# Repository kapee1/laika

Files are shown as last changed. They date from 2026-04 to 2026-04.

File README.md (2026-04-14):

# Laika - 45%-ish v4n4g0n-inspired keyboard  



### Build guide — *coming soon*

---

### Main features:

* Custom compact layout — 47 keys + half of number row
* Waveshare RP2040-Zero MCU
* MX hotswap
* Split spacebar support (2 × 3u or 1 x 6u)
* Two plate options: Standard and Extra (extra plate has enlarged stabilizers holes)
* Top mount with o-rings
* The two halves of the case and top weight are held together by magnets
* VIAL / QMK firmware

---

### Layout:

laika

---

## BOM:

| Part | Quantity |
|---|---|
| Laika PCB | 1 |
| Laika Case Top | 1 |
| Laika Case Bottom | 1 |
| Laika Plate (Standard or Extra) | 1 |
| Top Weight | 1 |
| Battery Cover (optional) | 1 |
| Waveshare RP2040-Zero | 1 |
| 1N4148W SOD-123 Diodes | 53 |
| MX-compatible switches | 53 |
| MX hotswap sockets | 53 |
| Stabilizers (PCB-mount) | 2x3u or 1x6u |
| M2 screws x 4 mm | 10 |
| M2 inserts OD:3.2, H:3 | 8 |
| Rubber feet 3M SJ5302 (8x8x2) | 4 |
| Magnets 5x3 | 14 |
| Magnets 5x1 | 4 |
| Silicone o-rings 5x2 | 8 |

---

## Files:

```
laika/
├── case/
│   ├── top.step                          # Top case
│   ├── bottom.step                       # Bottom case
│   ├── battery-cover.step                # Battery cover
│   ├── standart-plate.step               # Standard plate
│   ├── extra-plate.step                  # Extra plate
│   ├── top-weight (laika).step           # Top weight — "laika" text
│   └── top-weight (laika-the-keyboard).step  # Top weight — "laika the keyboard" text
├── laika-pcb/
│   ├── laika-pcb.kicad_pcb               # PCB layout (KiCad 10)
│   ├── laika-pcb.kicad_sch               # Schematic (KiCad 10)
│   ├── laika-pcb.kicad_pro               # KiCad project
│   └── Production files/
│       └── Laika PCB gerbers.zip         # Ready-to-order gerber files
└── plate-dxf/
    ├── standart-plate.dxf                # Standard plate for laser cutting / CNC
    └── extra-plate.dxf                   # Extra plate with enlarged stabilizers cutouts / CNC
```

---

## PCB manufacturing:

Send `laika-pcb/Production files/Laika PCB gerbers.zip` to your preferred PCB manufacturer (JLCPCB, PCBWay, etc.) with the following settings:

| Setting | Value |
|---|---|
| Layers | 2 |
| Thickness | 1.6 mm |
| Surface finish | HASL / ENIG |
| Color | your choice |

---

## Firmware:

Laika runs on **VIAL** (QMK fork with real-time key remapping — no flashing required for layout changes.

https://github.com/vial-kb/vial-qmk/tree/vial/keyboards/laika

**Flashing (RP2040-Zero):**
1. Hold the BOOT button on the RP2040-Zero while connecting USB.
2. A drive named `RPI-RP2` will appear.
3. Drop the `.uf2` firmware file onto that drive.
4. The keyboard will reboot and be ready to use.

---

## What is tested?

| Part | Is tested? |
|---|---|
| Top | Changed since proto, untested ⚠️ |
| Bottom | Changed since proto, untested ⚠️ |
| Standart plate | ✅  |
| Extra plate | Untested ⚠️ |
| Top weight | ✅ |
| PCB | ✅ |
| Battery cover | ✅ |

---

## Photos of PC proto:



photo_2025-11-13_11-15-49 (2)



---

*Named after Laika — the first living creature to orbit Earth.*

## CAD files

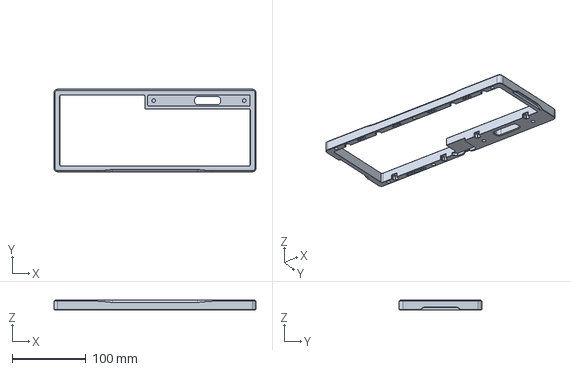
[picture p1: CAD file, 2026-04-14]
case/top.step
274.2 x 112.2 x 13.2 mm

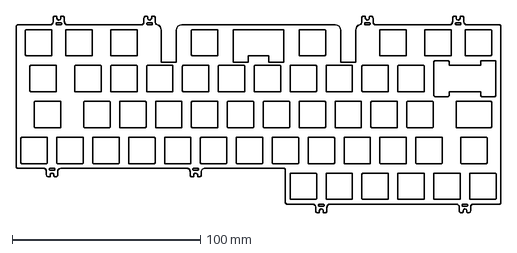
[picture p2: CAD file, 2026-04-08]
plate/extra-plate.dxf
257.2 x 104.2 mm

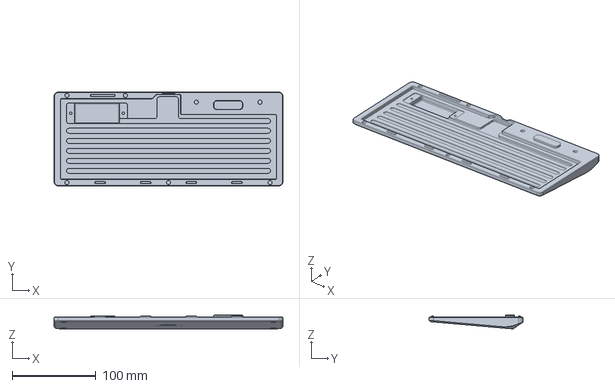
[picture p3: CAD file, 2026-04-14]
case/bottom.step
274.2 x 112.2 x 16.6 mm

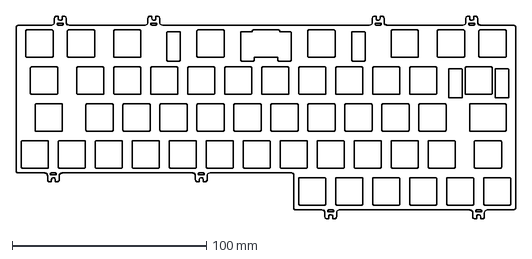
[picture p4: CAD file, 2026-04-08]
plate/standart-plate.dxf
257.2 x 104.2 mm

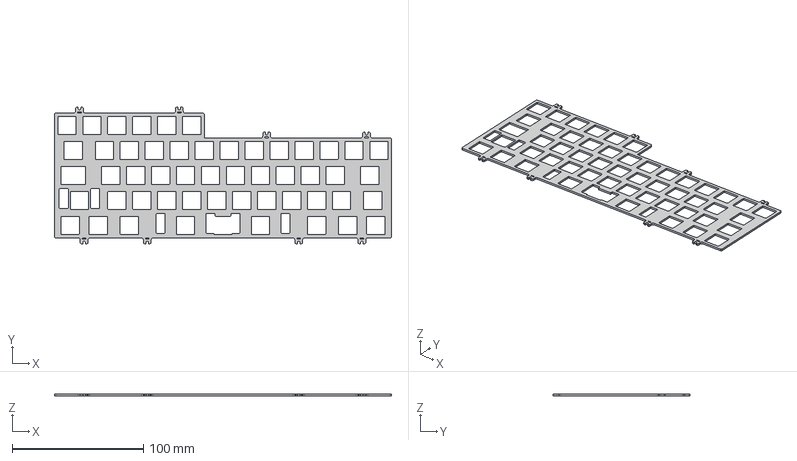
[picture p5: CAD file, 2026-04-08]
case/standart-plate.step
257.2 x 104.2 x 1.50 mm

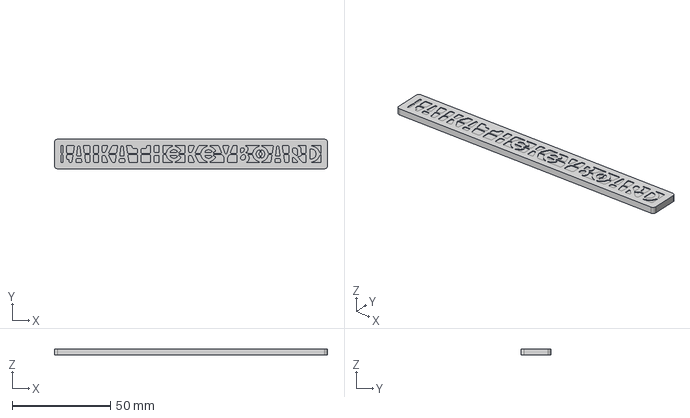
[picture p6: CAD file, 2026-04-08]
case/top-weight (laika-the-keyboard).step
138.9 x 15.0 x 3.00 mm

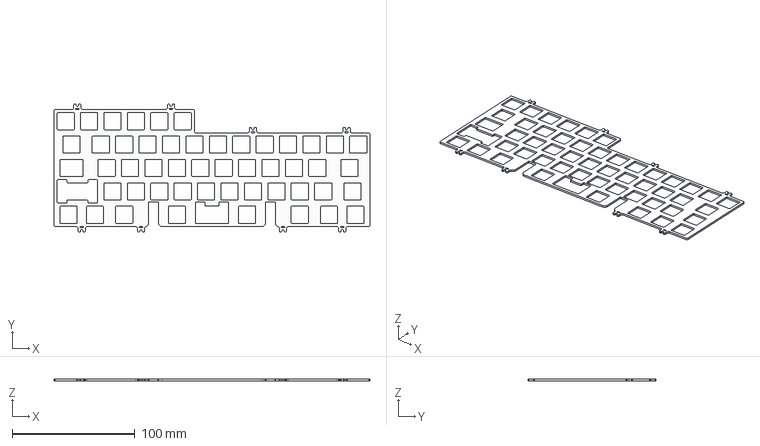
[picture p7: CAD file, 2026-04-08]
case/extra-plate.step
257.2 x 104.2 x 1.50 mm

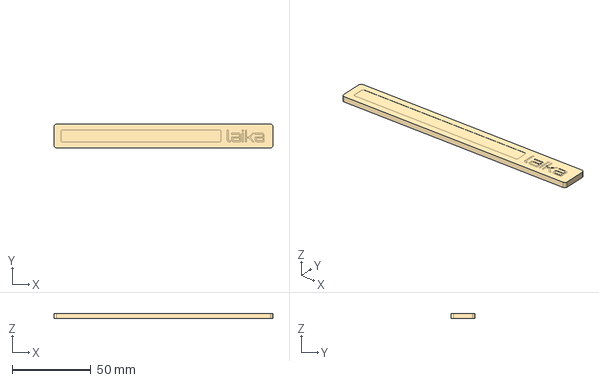
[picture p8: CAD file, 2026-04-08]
case/top-weight (laika).step
138.9 x 15.0 x 3.00 mm

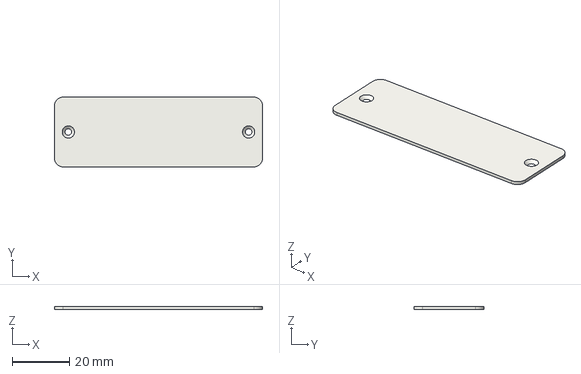
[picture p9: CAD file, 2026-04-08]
case/battery-cover.step
72.7 x 24.4 x 1.00 mm

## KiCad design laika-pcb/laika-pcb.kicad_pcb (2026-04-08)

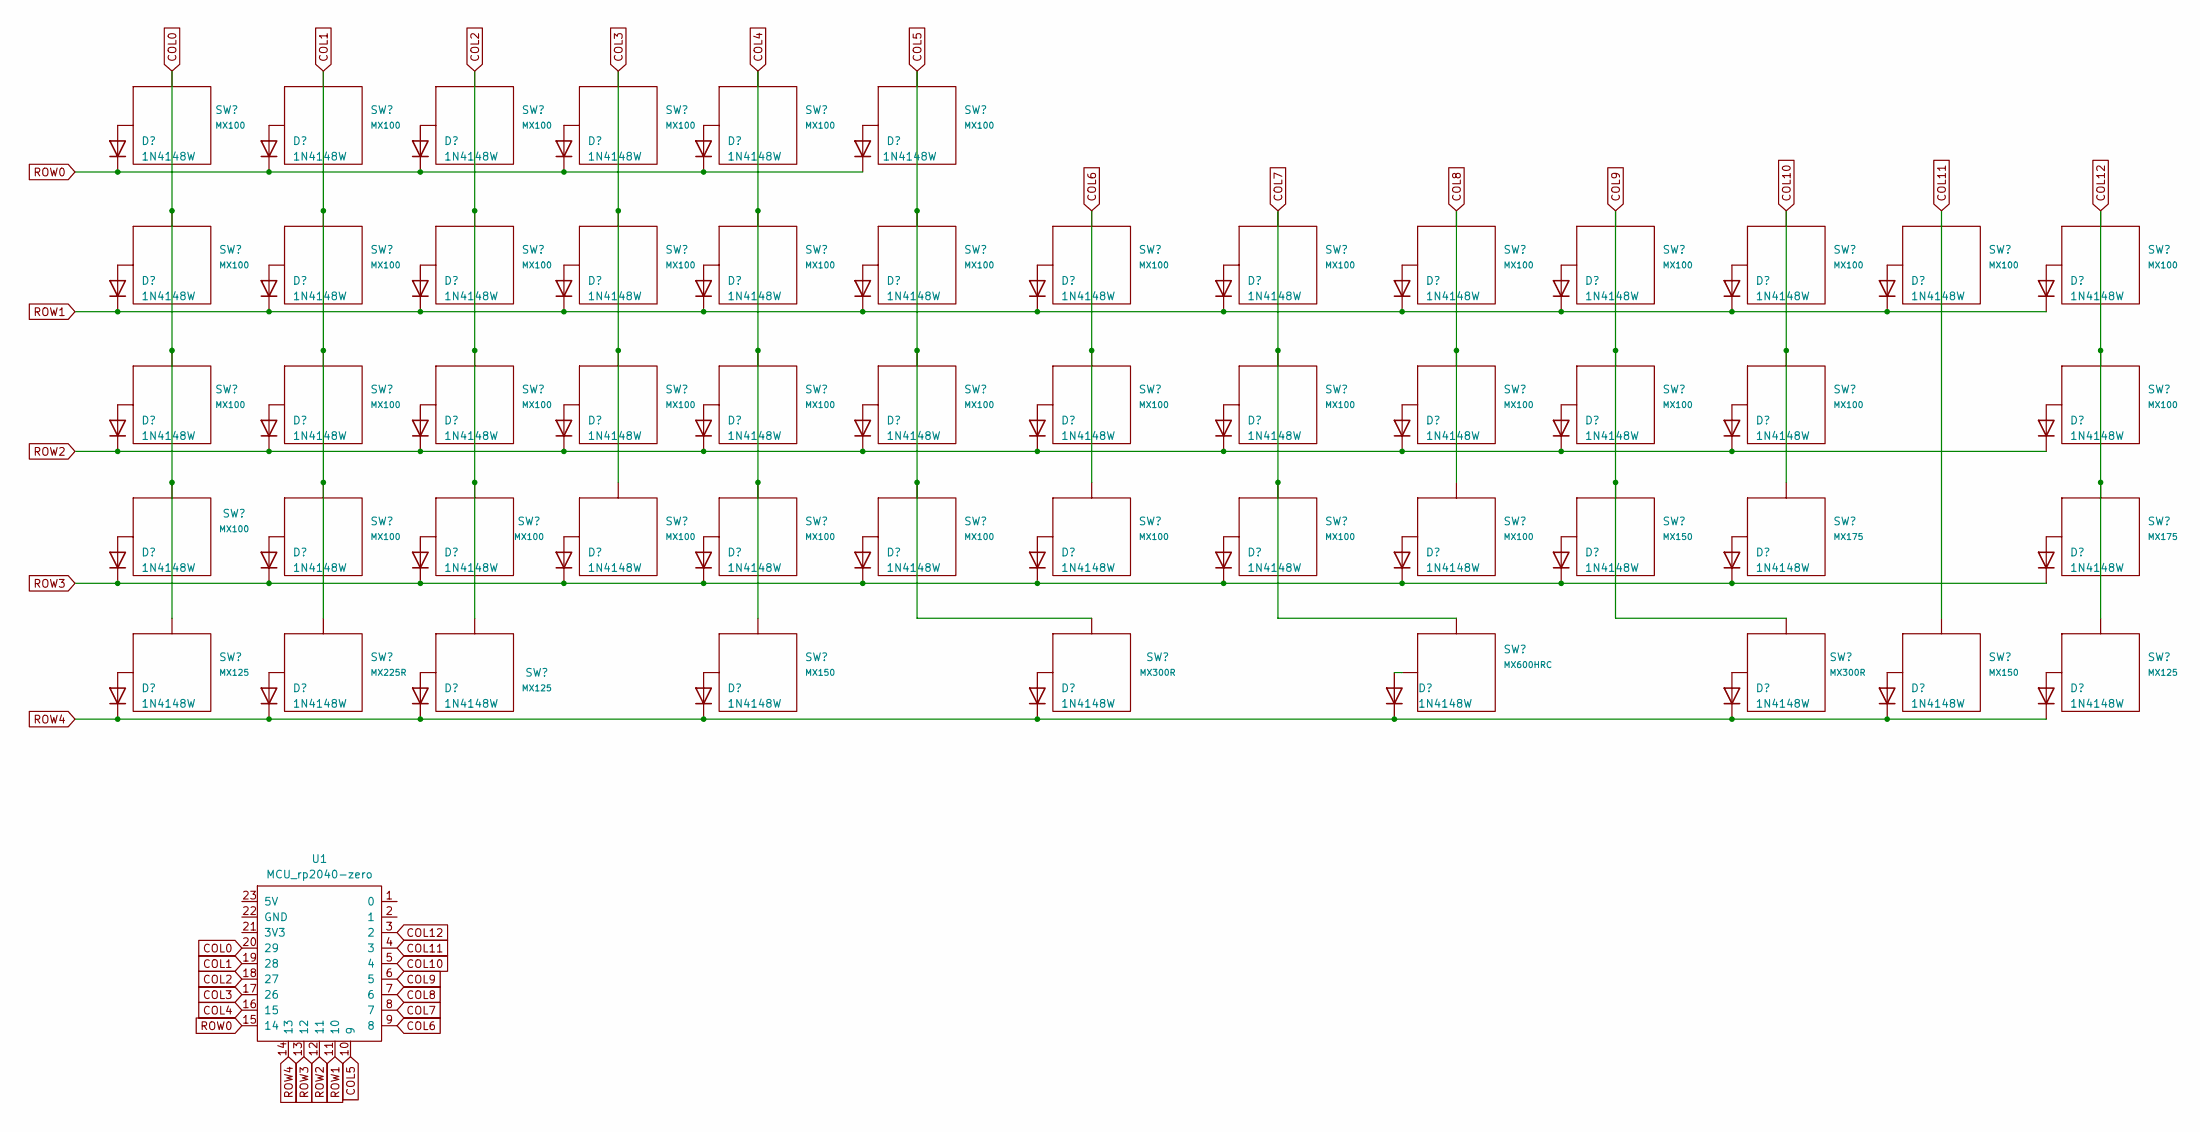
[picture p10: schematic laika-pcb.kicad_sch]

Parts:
D1, D2, D3, D4, D5, D6, D7, D8, D9, D10, D11, D12, D13, D14, D15, D16, D17, D18, D19, D20, D21, D22, D23, D24, D25, D26, D27, D28, D29, D30, D31, D32, D33, D34, D35, D36, D37, D38, D39, D40, D41, D42, D43, D44, D45, D46, D47, D48, D49, D50, D51, D52: 1N4148W; D_SOD-123
SW1, SW2, SW3, SW4, SW5, SW6, SW8, SW9, SW10, SW11, SW12, SW13, SW14, SW15, SW16, SW17, SW18, SW19, SW21, SW22, SW23, SW24, SW25, SW26, SW27, SW28, SW29, SW30, SW33, SW34, SW35, SW36, SW37, SW38, SW39, SW40: MX100; MX100H
SW7: MX100; MX150H
SW20, SW31: MX100; MX175H
SW32: MX100; MX200HR
SW41, SW51: MX150; MX100H
SW42: MX175; MX100H
SW43: MX175; MX150H
SW44, SW52: MX125; MX125H
SW45: MX225R; MX100H
SW46: MX125; MX150H
SW47: MX150; MX300HR
SW48: MX300R; MX600HRС
SW49: MX600HRC; MX300HR
SW50: MX300R; MX150H
U1: MCU_rp2040-zero; MCU_rp2040-zero-smd_reversed

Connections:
COL0: SW1.2 (Row), SW7.2 (Row), SW20.2 (Row), SW32.2 (Row), SW44.2 (Row), U1.20 (29); also elsewhere on the board
COL1: SW2.2 (Row), SW8.2 (Row), SW21.2 (Row), SW33.2 (Row), SW45.2 (Row), U1.19 (28)
COL2: SW3.2 (Row), SW9.2 (Row), SW22.2 (Row), SW34.2 (Row), SW46.2 (Row), U1.18 (27)
COL3: SW4.2 (Row), SW10.2 (Row), SW23.2 (Row), SW35.2 (Row), U1.17 (26)
COL4: SW5.2 (Row), SW11.2 (Row), SW24.2 (Row), SW36.2 (Row), SW47.2 (Row), U1.16 (15)
COL5: SW6.2 (Row), SW12.2 (Row), SW25.2 (Row), SW37.2 (Row), SW48.2 (Row), U1.10 (9)
COL6: SW13.2 (Row), SW26.2 (Row), SW38.2 (Row), U1.9 (8)
COL7: SW14.2 (Row), SW27.2 (Row), SW39.2 (Row), SW49.2 (Row), U1.8 (7)
COL8: SW15.2 (Row), SW28.2 (Row), SW40.2 (Row), U1.7 (6)
COL9: SW16.2 (Row), SW29.2 (Row), SW41.2 (Row), SW50.2 (Row), U1.6 (5)
COL10: SW17.2 (Row), SW30.2 (Row), SW42.2 (Row), U1.5 (4)
COL11: SW18.2 (Row), SW51.2 (Row), U1.4 (3)
COL12: SW19.2 (Row), SW31.2 (Row), SW43.2 (Row), SW52.2 (Row), U1.3 (2)
unnamed: D1.2 (A), SW1.1 (Col)
unnamed: D2.2 (A), SW2.1 (Col)
unnamed: D3.2 (A), SW3.1 (Col)
unnamed: D4.2 (A), SW4.1 (Col)
unnamed: D5.2 (A), SW5.1 (Col)
unnamed: D6.2 (A), SW6.1 (Col)
unnamed: D7.2 (A), SW7.1 (Col)
unnamed: D8.2 (A), SW8.1 (Col)
unnamed: D9.2 (A), SW9.1 (Col)
unnamed: D10.2 (A), SW10.1 (Col)
unnamed: D11.2 (A), SW11.1 (Col)
unnamed: D12.2 (A), SW12.1 (Col)
unnamed: D13.2 (A), SW13.1 (Col)
unnamed: D14.2 (A), SW14.1 (Col)
unnamed: D15.2 (A), SW15.1 (Col)
unnamed: D16.2 (A), SW16.1 (Col)
unnamed: D17.2 (A), SW17.1 (Col)
unnamed: D18.2 (A), SW18.1 (Col)
unnamed: D19.2 (A), SW19.1 (Col)
unnamed 32: D20.2 (A), SW20.1 (Col); also elsewhere on the board
unnamed: D21.2 (A), SW21.1 (Col)
unnamed: D22.2 (A), SW22.1 (Col)
unnamed: D23.2 (A), SW23.1 (Col)
unnamed: D24.2 (A), SW24.1 (Col)
unnamed: D25.2 (A), SW25.1 (Col)
unnamed: D26.2 (A), SW26.1 (Col)
unnamed: D27.2 (A), SW27.1 (Col)
unnamed: D28.2 (A), SW28.1 (Col)
unnamed: D29.2 (A), SW29.1 (Col)
unnamed: D30.2 (A), SW30.1 (Col)
unnamed: D31.2 (A), SW31.1 (Col)
unnamed: D32.2 (A), SW32.1 (Col)
unnamed: D33.2 (A), SW33.1 (Col)
unnamed: D34.2 (A), SW34.1 (Col)
unnamed: D35.2 (A), SW35.1 (Col)
unnamed: D36.2 (A), SW36.1 (Col)
unnamed: D37.2 (A), SW37.1 (Col)
unnamed: D38.2 (A), SW38.1 (Col)
unnamed: D39.2 (A), SW39.1 (Col)
unnamed: D40.2 (A), SW40.1 (Col)
unnamed: D41.2 (A), SW41.1 (Col)
unnamed: D42.2 (A), SW42.1 (Col)
unnamed: D43.2 (A), SW43.1 (Col)
unnamed: D44.2 (A), SW44.1 (Col)
unnamed: D45.2 (A), SW45.1 (Col)
unnamed: D46.2 (A), SW46.1 (Col)
unnamed: D47.2 (A), SW47.1 (Col)
unnamed: D48.2 (A), SW48.1 (Col)
unnamed: D49.2 (A), SW49.1 (Col)
unnamed: D50.2 (A), SW50.1 (Col)
unnamed: D51.2 (A), SW51.1 (Col)
unnamed: D52.2 (A), SW52.1 (Col)
ROW0: D1.1 (K), D2.1 (K), D3.1 (K), D4.1 (K), D5.1 (K), D6.1 (K), U1.15 (14)
ROW1: D7.1 (K), D8.1 (K), D9.1 (K), D10.1 (K), D11.1 (K), D12.1 (K), D13.1 (K), D14.1 (K), D15.1 (K), D16.1 (K), D17.1 (K), D18.1 (K), D19.1 (K), U1.11 (10)
ROW2: D20.1 (K), D21.1 (K), D22.1 (K), D23.1 (K), D24.1 (K), D25.1 (K), D26.1 (K), D27.1 (K), D28.1 (K), D29.1 (K), D30.1 (K), D31.1 (K), U1.12 (11)
ROW3: D32.1 (K), D33.1 (K), D34.1 (K), D35.1 (K), D36.1 (K), D37.1 (K), D38.1 (K), D39.1 (K), D40.1 (K), D41.1 (K), D42.1 (K), D43.1 (K), U1.13 (12)
ROW4: D44.1 (K), D45.1 (K), D46.1 (K), D47.1 (K), D48.1 (K), D49.1 (K), D50.1 (K), D51.1 (K), D52.1 (K), U1.14 (13)

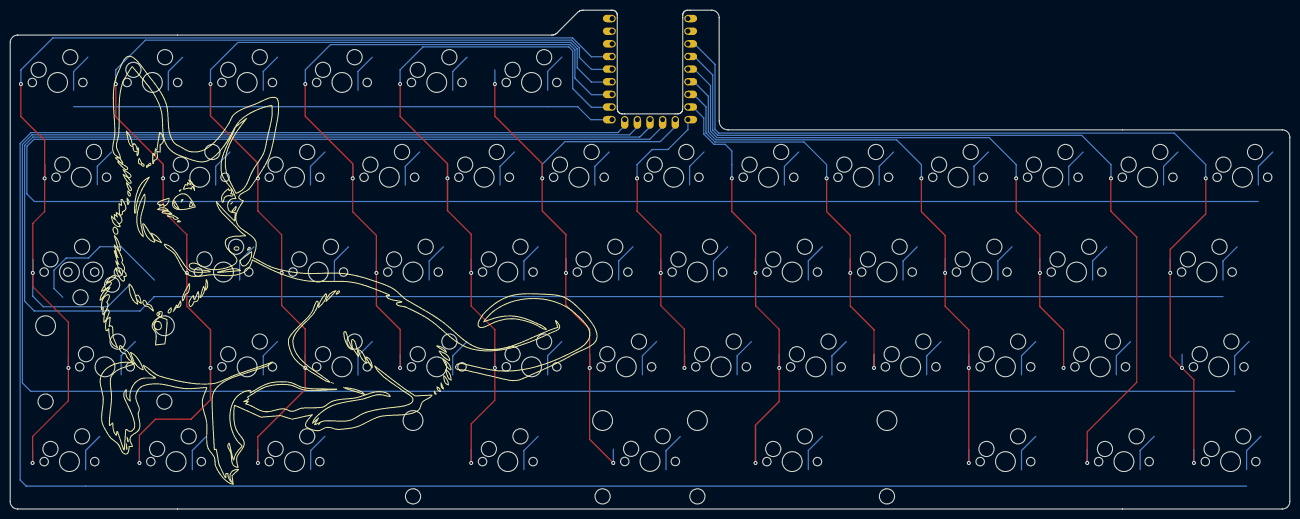
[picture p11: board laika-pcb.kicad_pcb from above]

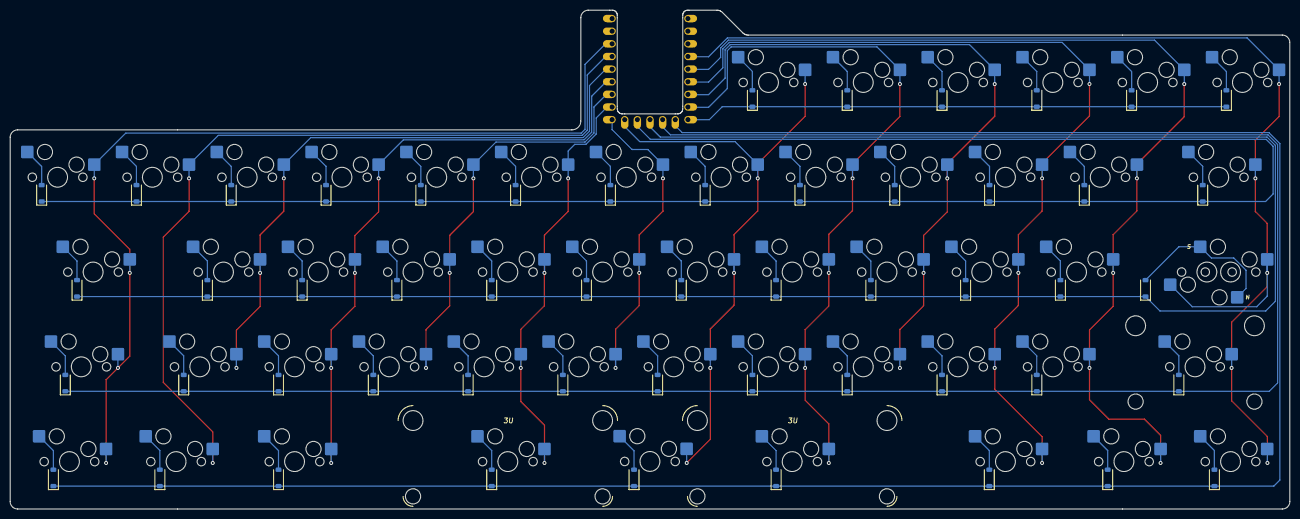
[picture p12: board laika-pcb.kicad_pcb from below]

Board: 2 copper layers, 257.2 x 100.2 mm, 106 parts (52 on the bottom side), 70 nets.

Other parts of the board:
SW53: MXH125; MX125H

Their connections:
COL0: SW53.2; also elsewhere on the board
unnamed 32: SW53.1; also elsewhere on the board

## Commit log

2026-04-08 Add all project files: firmware, case, PCB, plate
    [battery-cover.step, bottom.step, extra-plate.dxf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]
2026-04-09 Revise README for Laika keyboard specifications
    Updated README with new images, feature list, and BOM details.
2026-04-09 Revise README to include top mount and magnet details
    Updated features and specifications in the README.
2026-04-14 small fixes in top and bottom
    [bottom.step, top.step]
2026-04-14 Enhance README with detailed specifications and testing info
    Updated README with additional details on plate options, M2 inserts, and testing status.
